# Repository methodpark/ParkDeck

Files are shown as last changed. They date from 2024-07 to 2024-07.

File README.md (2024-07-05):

# ParkDeck

## Description
ParkDeck is MethodPark's version of a streamdeck. With it you can control desktop applications on your pc or send macros for all number of purposes!

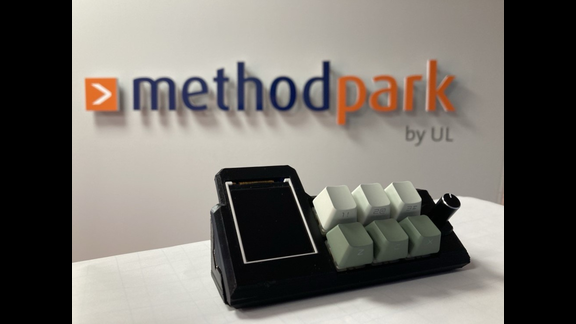
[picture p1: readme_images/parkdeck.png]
ParkDeck


In this repository you can find all information on how to build a ParkDeck. The code and the Readme are set up to control Spotify streaming.

## Prerequisite

- **Arduino IDE with a version > 2.0**
- You can check the version of your Arduino IDE by navigating to the topbar in the IDE and selecting `Help` -> `About Arduino IDE`
- Download and install the Arduino IDE following the instructions for your OS, [here](https://www.arduino.cc/en/software)

## Assembly

Place the ESP dev module on the PCB and solder it in place.

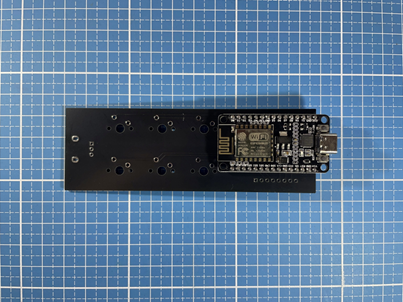
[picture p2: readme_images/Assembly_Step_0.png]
Assembly_Step_0


Flip it and place the switches and potentiometer on the PCB and solder them.

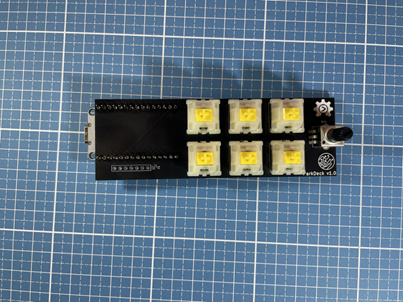
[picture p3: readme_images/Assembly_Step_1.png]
Assembly_Step_1


Place the LCD in the front half of the case. Don't forget to remove the protective peel beforehand!

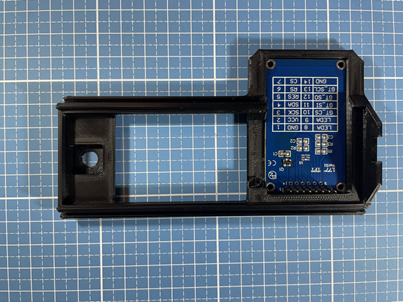
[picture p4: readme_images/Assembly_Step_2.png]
Assembly_Step_2


Place the PCB into the front half of the case and align the LCD pins. Then solder it in place.

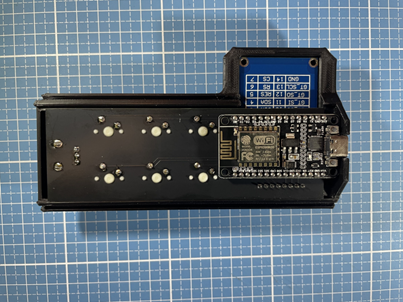
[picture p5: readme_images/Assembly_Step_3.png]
Assembly_Step_3


Slide the two halves of the case together.

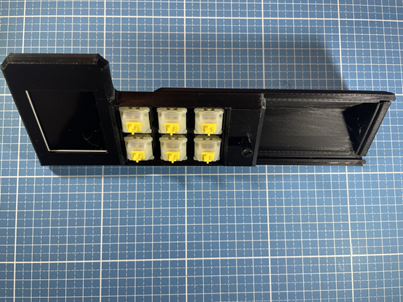
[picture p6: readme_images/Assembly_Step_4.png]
Assembly_Step_4


Choose and put the switch caps of your choice and put the potentiometer knob in place.

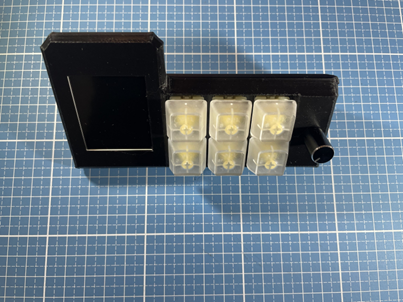
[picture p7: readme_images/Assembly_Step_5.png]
Assembly_Step_5


The hardware assembly is now done!

## Setup
- Clone this repository and open the .ino file in the Arduino IDE
- Install the following libraries by navigating to `Sketch` -> `Include Library` -> `Manage Libraries` or press `CTRL` + `SHIFT` + `I` and type in the name of the libraries:
	- `TFT_eSPI` by Bodmer
	TFT_eSPI library by Bodmer
	- `TJpg_Decoder` by Bodmer
	TJpg_Decoder
	- `ArduinoJson` by Benoit Blanchon
	ArduinoJson
- Go to the [filesystem plugin for ESP8266 repository](https://github.com/earlephilhower/arduino-littlefs-upload) and follow the installation instructions and then come back after restarting the IDE

At this point, all neccessary libraries should be installed. Next, we want to connect the ParkDeck and check that everything is working.

- Plug in your assembled ParkDeck
- In the IDE, navigate to `File` -> `Preferences`, look for `Additional Boards Manager URLs` or press `CTRL` + `,` and click the popup icon at the end of the line. Add the URL `http://arduino.esp8266.com/stable/package_esp8266com_index.json` and confirm your settings.

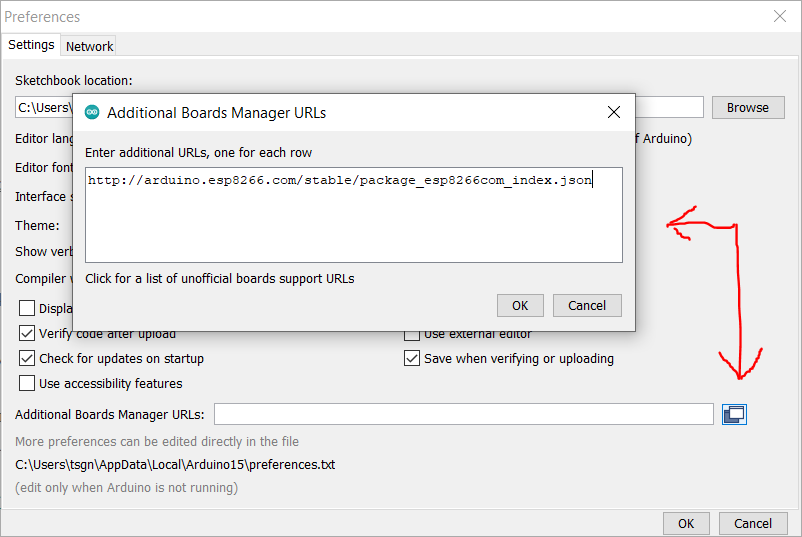
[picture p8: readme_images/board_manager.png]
Adding the ESP8266 Board Manager URL


- Navigate to `Tools` -> `Board` -> `Boards Manager...`, and install the `esp8266`
- Navigate to `Tools` -> `Board` -> `ESP8266 Boards` and select `NodeMCU 1.0 (ESP-12E Module)`
- Set `Tools` -> `CPU Frequency` to `160mhz`
- Navigate to `Tools` -> `Port` and select the correct port. This depends on where you've plugged in the ParkDeck. Find the right port by selecting one (e.g. `COM7`) and try to upload the sketch using the arrow icon in the toolbar. A success looks like this:
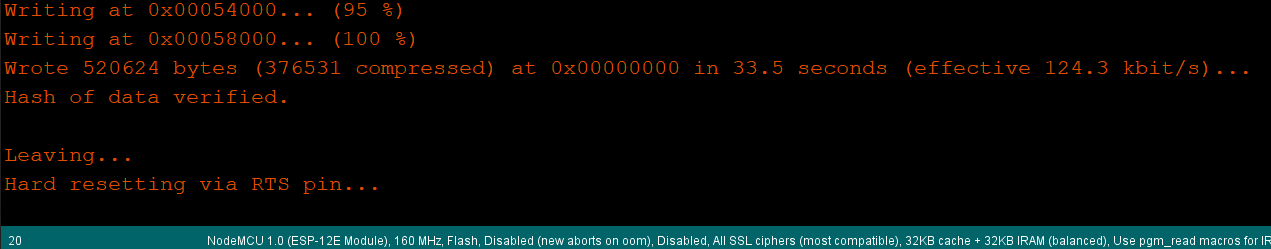
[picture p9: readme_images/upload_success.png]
Upload success

- Now you can upload the data inside the `data` folder in this repository to the ESP. Use the command `[Ctrl] + [Shift] + [P], then "Upload LittleFS to Pico/ESP8266/ESP32"` and wait for it to finish. Note: make sure that no serial monitor or serial plot is open in order for this tool to work.

Next, we need to make a few configuration changes to the libraries we've installed to make the display work.

- Open the Arduino TFT library installation folder. On Windows, it is located at `Documents\Arduino\libraries\TFT_eSPI`
- Open the `User_Setup_Select.h` file in an editor of your choice
- Add `//` in front of line 27 (`// #include <User_Setup.h)` to comment the line and uncomment by removing the `//` in line 30 to include the `User_Setups/Setup2_ST7735.h` and save your changes
TFT_eSPI_configuration
- Next, open the `Setup2_ST7735.h` file in an editor of your choice located in the folder `User_Setups` and change line 11 from `#define ST7735_REDTAB` to `#define ST7735_GREENTAB`.
- Add `#define TFT_SPI_OVERLAP` after `TFT_HEIGHT` in line 9
- Uncomment line 16 `#define TFT_RGB_ORDER TFT_RGB  // Colour order Red-Green-Blue`
- In the same file, replace lines 20 - 22 with the correct pins and save the file:
```
#define TFT_CS   PIN_D3  // Chip select control pin D8
#define TFT_DC   PIN_D8  // Data Command control pin
#define TFT_RST  PIN_D6  // Reset pin
#define TFT_MISO  PIN_MISO  // MISO
#define TFT_MOSI  PIN_MOSI  // MOSI
#define TFT_SCLK  PIN_SCLK  // CLK
```
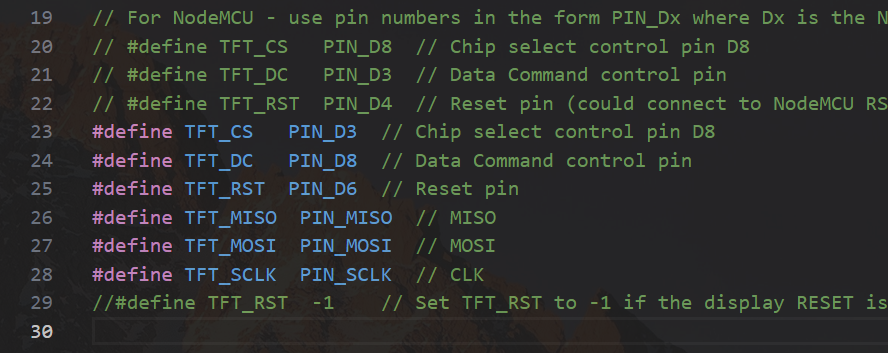
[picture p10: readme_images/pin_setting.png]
pin_setting


Congratulations! Everything should be correctly set up. The only thing left is to make sure that your ParkDeck is connected to your WIFI and make sure it works.

- In the ParkDeck.ino file edit lines 40 and 41 to your WIFI_SSID and PASSWORD.
	> Note: SSIDs are case sensitive.
- Upload the code to the ParkDeck

If it worked the screen should show its personal IP adress once the ParkDeck has rebooted.

## Spotify setup
- Go to https://developer.spotify.com/documentation/web-api and follow the instructions there to create a new app.
- When asked for a redirect URI enter `http://YOUR_ESP_IP/callback`, where `YOUR_ESP_IP` is the IP displayed on the screen of the ParkDeck in the step before.
- In the Spotify app there are client_ID as well as client_Secret, copy these to line 44 and 45 in the ParkDeck.ino file.
- Also enter the IP adress from above as `YOUR_ESP_IP` in line 46.
- Push the code once more in Arduino IDE and once your ParkDeck reboots navigate in a web browser to the IP displayed and follow the instructions.

It's done! Now you can start Spotify and enjoy the control you have with your new ParkDeck!

## Notes

- You have to authenticate on each usage (each restart)
- Skip backwards works only after the songs is playing a few seconds, the ParkDeck needs to load the album art etc.

## Original source
Credit goes to https://gitlab.com/makeitforless/spotify_controller for the idea and framework.

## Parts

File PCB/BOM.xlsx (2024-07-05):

Type | Description | # needed | Link
Display | Display | 1 | https://www.amazon.de/AZDelivery-TFT-Display-128x160-Pixeln-Arduino/dp/B07FYCKYP1/
ESP8266 | ESP8266 | 1 | https://www.amazon.de/Entwicklungsboard-RUIZHI-Schnittstelle-kompatibel-Micropython/dp/B0CLXZ9VN9/
10k Pot | Potentiometer | 1 | https://www.amazon.de/sourcing-map-Potentiometer-Varistor-Kohleschicht/dp/B07TBG7XHZ/
Knob | Potentiometer knob | 1 | https://www.amazon.de/sourcing-map-Potentiometerknopf-R%C3%A4ndelwelle-Lautst%C3%A4rkeregler/dp/B08214YZDS
Switch | Switch | 6 | https://www.amazon.de/Mechanische-Dedizierte-Professionellem-Tastaturabzieher-mechanische/dp/B096SS742W/
Switch Cap | Coloured | 6 | https://www.amazon.de/Elacgap-Profile-switches-Mechanical-Keyboard-Verschiedene-Farben/dp/B0CQ2WGP2N/ (https://www.amazon.de/Mechanische-Dedizierte-Professionellem-Tastaturabzieher-mechanische/dp/B096SS742W/)
Switch Cap | Black |  | https://www.amazon.de/Elacgap-Profile-switches-Mechanical-Keyboard-Verschiedene-Farben/dp/B0CQ2XG16M/
Switch Cap | Transparent |  | https://www.amazon.de/Elacgap-Profile-switches-Mechanical-Keyboard-Verschiedene-Farben/dp/B0CQ2Y89GQ/
Cable | Cable | 1 | https://www.amazon.de/QGhappy-Ladekabel-geflochtene-Datenkabel-Schnellladekabell-Rot/dp/B07JDP2MNB/
PCB | PCB | 1
Anti Slip | Anti Slip |  | https://www.amazon.de/Silikon-Rutschfest-Selbsthaftender-Gro%C3%9Fartig-geeignet/dp/B071CGN92T/
Resistor | Resistor | 1 | https://www.amazon.de/Innfeeltech-Toleranz-Widerstand-Projekt-Experimente/dp/B0CL73CZPQ/

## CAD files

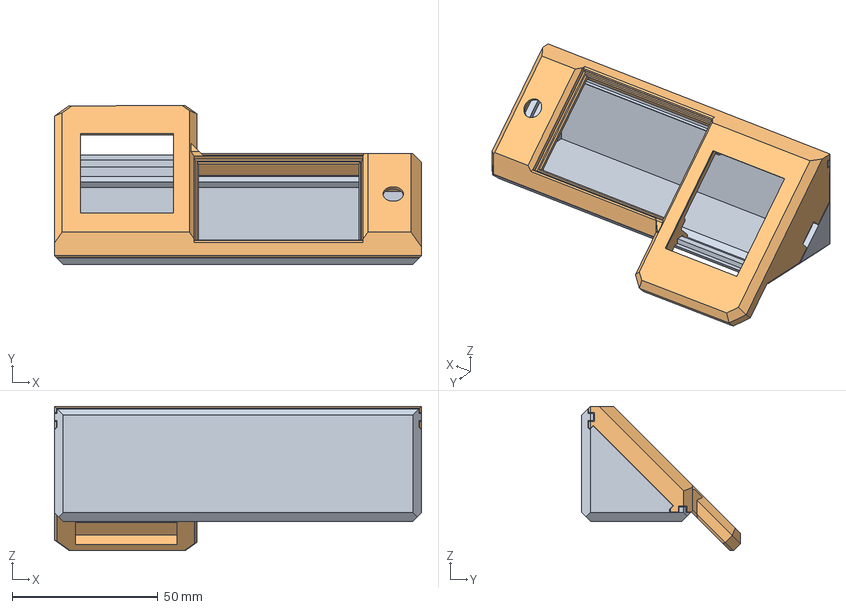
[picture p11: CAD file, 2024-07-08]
models/ParkDeck.step
125.8 x 54.5 x 49.5 mm

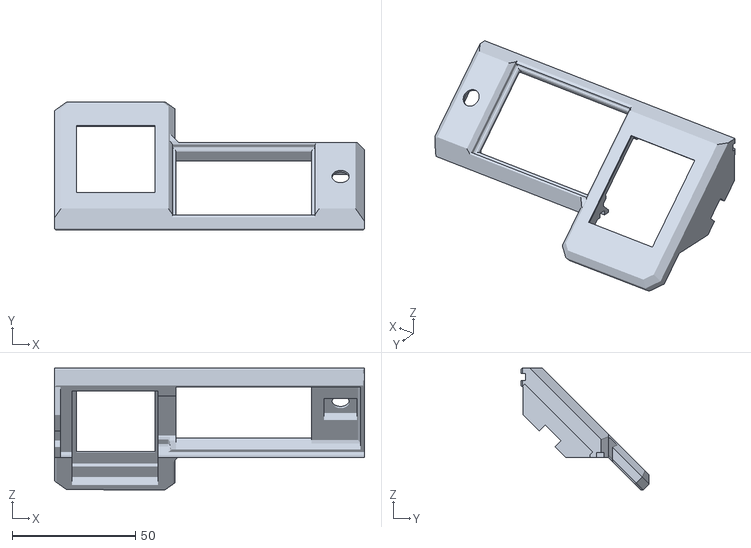
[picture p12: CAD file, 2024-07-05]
models/ParkDeck_Top.stl
125.8 x 52.1 x 49.5

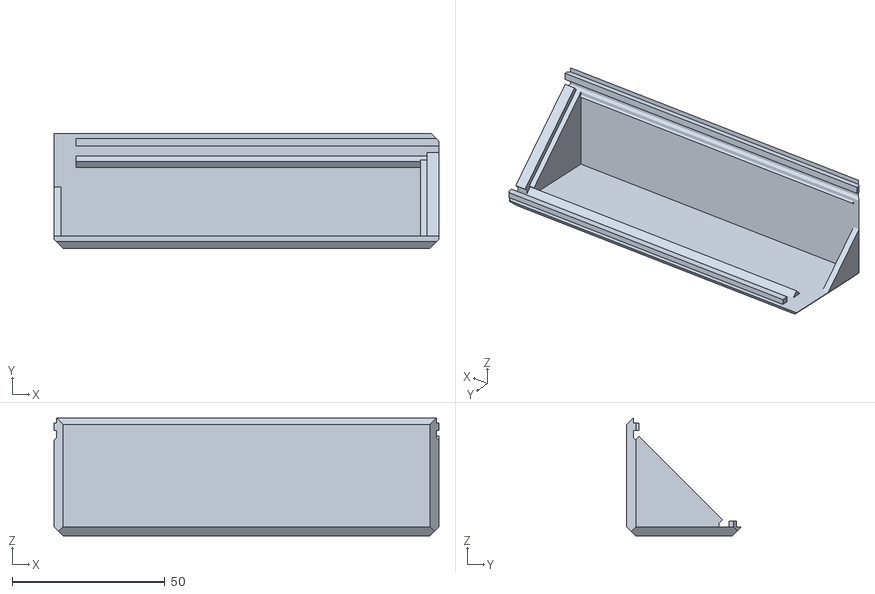
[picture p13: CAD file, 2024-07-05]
models/ParkDeck_Base.stl
125.8 x 37.5 x 38.6

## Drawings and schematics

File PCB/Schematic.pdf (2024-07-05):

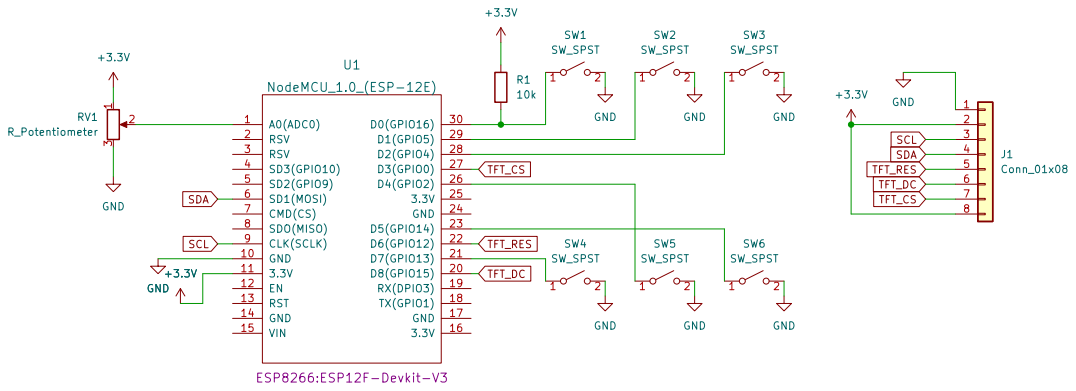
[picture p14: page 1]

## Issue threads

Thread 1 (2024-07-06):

Source file for the case

dgrabla, 2024-07-06:
Terrific project, thanks

Hey @LeJokester any chance we can get a step file || onshape link || fusion360 to do remixes of the case?
I would like to hook it somehow under the display and use it 'upside down'.
I could not find the model on printables or thingiverse.

Best

LeJokester, 2024-07-08:
Glad you like it! I added the case model as step and fbx files, I hope that helps :)

dgrabla, 2024-07-08:
Great, thanks!

Closed 2024-07-08.

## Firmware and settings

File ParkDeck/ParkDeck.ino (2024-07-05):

/*========================================
|Include all libraries needed for program|
========================================*/

// Include the jpeg decoder library
#include <TJpg_Decoder.h>

// Include LittleFS
#include <FS.h>
#include <LittleFS.h>

//Include JSON
#include <ArduinoJson.h>

//Include base 64 encode
#include <base64.h>

// Include WiFi and http client
#include <ESP8266WiFi.h>
#include <ESP8266HTTPClient.h>
#include <ESP8266WebServer.h>
#include <WiFiClientSecureBearSSL.h>

// Load tabs attached to this sketch
#include "List_SPIFFS.h"
#include "Web_Fetch.h"
#include "index.h"
#include "SpotifyConnection.h"

// Include the TFT library https://github.com/Bodmer/TFT_eSPI
#include <SPI.h>
#include <TFT_eSPI.h>

/*=========================
|User modifiable variables|
=========================*/

// WiFi credentials
#define WIFI_SSID "WIFI_SSID"
#define PASSWORD "PASSWORD"

// Spotify API credentials
#define CLIENT_ID "CLIENT_ID"
#define CLIENT_SECRET "CLIENT_SECRET"
#define REDIRECT_URI "http://YOUR_ESP_IP/callback"

/*=========================
|Non - modifiable variables|
==========================*/

//Vars for keys, play state, last song, etc.
bool buttonStates[] = { 1, 1, 1, 1, 1, 1 };
int debounceDelay = 50;
unsigned long debounceTimes[] = { 0, 0, 0, 0, 0, 0 };
int buttonPins[] = { D0, D1, D2, D7, D4, D5 };
int trackRefreshTimeInMilliseconds = 5000;

//Object instances
ESP8266WebServer server(80);  //Server on port 80
TFT_eSPI tft = TFT_eSPI();  // Invoke custom library
SpotifyConnection spotifyConnection(CLIENT_ID, CLIENT_SECRET, REDIRECT_URI, tft);

int imageOffsetX = 26, imageOffsetY = 20;

long timeLoop;
long refreshLoop;
bool serverOn = true;

//Web server callbacks
void handleRoot() {
  Serial.println("handling root");
  char page[500];
  sprintf(page, mainPage, CLIENT_ID, REDIRECT_URI);
  server.send(200, "text/html", String(page) + "\r\n");  //Send web page
}

void handleCallbackPage() {
  if (!spotifyConnection.accessTokenSet) {
    if (server.arg("code") == "") {  //Parameter not found
      char page[500];
      sprintf(page, errorPage, CLIENT_ID, REDIRECT_URI);
      server.send(200, "text/html", String(page));  //Send web page
    } else {
      //Parameter found
      if (spotifyConnection.getUserCode(server.arg("code"))) {
        server.send(200, "text/html", "Spotify setup complete Auth refresh in :" + String(spotifyConnection.tokenExpireTime));
      } else {
        char page[500];
        sprintf(page, errorPage, CLIENT_ID, REDIRECT_URI);
        server.send(200, "text/html", String(page));  //Send web page
      }
    }
  } else {
    server.send(200, "text/html", "Spotify setup complete");
  }
}

// This next function will be called during decoding of the jpeg file to
// render each block to the TFT.  If you use a different TFT library
// you will need to adapt this function to suit.
bool tft_output(int16_t x, int16_t y, uint16_t w, uint16_t h, uint16_t *bitmap) {
  // Stop further decoding as image is running off bottom of screen
  if (y >= tft.height()) {
    return 0;
  }

  // This function will clip the image block rendering automatically at the TFT boundaries
  tft.pushImage(x, y, w, h, bitmap);

  // Return 1 to decode next block
  return 1;
}

/*==============
|Setup function|
==============*/
// * Sets up WiFi
// * Initializes screen
// * Shows Ip on screen

void setup() {
  Serial.begin(115200);

  // Initialise LittleFS
  if (!LittleFS.begin()) {
    Serial.println("LittleFS initialisation failed!");
    while (1) yield();  // Stay here twiddling thumbs waiting
  }
  Serial.println("\r\nInitialisation done.");

  // Initialise the TFT
  tft.begin();
  tft.fillScreen(TFT_BLACK);
  tft.setRotation(2);
  // The jpeg image can be scaled by a factor of 1, 2, 4, or 8
  TJpgDec.setJpgScale(4);

  // The byte order can be swapped (set true for TFT_eSPI)
  TJpgDec.setSwapBytes(true);

  // The decoder must be given the exact name of the rendering function above
  TJpgDec.setCallback(tft_output);

  WiFi.begin(WIFI_SSID, PASSWORD);
  while (WiFi.status() != WL_CONNECTED) {
    delay(1000);
    Serial.println("Connecting to WiFi...");
  }
  Serial.println("Connected to WiFi\n Ip is: ");
  Serial.println(WiFi.localIP());

  server.on("/", handleRoot);                  //Which routine to handle at root location
  server.on("/callback", handleCallbackPage);  //Which routine to handle at root location
  server.begin();                              //Start server
  Serial.println("HTTP server started");
  for (int i = 0; i < 6; i++) {
    pinMode(buttonPins[i], INPUT_PULLUP);
  }

  tft.println(WiFi.localIP());
  Serial.println("Setup done");
}

void loop() {
  if (!spotifyConnection.accessTokenSet) {
    server.handleClient();
    return;
  }

  if (serverOn) {
    server.close();
    serverOn = false;
  }

  if ((millis() - spotifyConnection.tokenStartTime) / 1000 > spotifyConnection.tokenExpireTime) {
    Serial.println("refreshing token");
    if (spotifyConnection.refreshAuth()) {
      Serial.println("refreshed token");
    }
  }

  if ((millis() - refreshLoop) > trackRefreshTimeInMilliseconds) {
    spotifyConnection.getTrackInfo();

    refreshLoop = millis();
  }

  for (int i = 0; i < 6; i++) {
    int reading = digitalRead(buttonPins[i]);
    if (reading != buttonStates[i]) {
      if (millis() - debounceTimes[i] > debounceDelay) {
        buttonStates[i] = reading;
        if (reading == LOW) {
          switch (i) {
            case 0:
              Serial.println("Button 0: not in use");
              //listSPIFFS();
              break;
            case 1:
              Serial.println("Button 1: toggleLiked");
              spotifyConnection.toggleLiked(spotifyConnection.currentSong.Id);
              break;
            case 2:
              Serial.println("Button 2: not in use");
              break;
            case 3:
              Serial.println("Button 3: skipBack");
              spotifyConnection.skipBack();
              break;
            case 4:
              Serial.println("Button 4 togglePlay");
              spotifyConnection.togglePlay();
              break;
            case 5:
              Serial.println("Button 5 skipForward");
              spotifyConnection.skipForward();
              break;
            default:
              break;
          }
        }
        debounceTimes[i] = millis();
      }
    }
  }

  int volumeRequest = map(analogRead(A0), 0, 1023, 100, 0);
  if (abs(volumeRequest - spotifyConnection.currVol) > 2) {
    spotifyConnection.adjustVolume(volumeRequest);
  }
  timeLoop = millis();
}

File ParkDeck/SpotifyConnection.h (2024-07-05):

// Include the TFT library https://github.com/Bodmer/TFT_eSPI
#include <SPI.h>
#include <TFT_eSPI.h>


class SpotifyConnection {
public:
  SpotifyConnection(String _CLIENT_ID, String _CLIENT_SECRET, String _REDIRECT_URI, TFT_eSPI &_tft): tft (_tft) {
    CLIENT_ID = _CLIENT_ID;
    CLIENT_SECRET = _CLIENT_SECRET;
    REDIRECT_URI = _REDIRECT_URI;
    client = std::make_unique<BearSSL::WiFiClientSecure>();
    client->setInsecure();

    for (int i = 0; i < 10; i++) {
      parts[i] = (char *)malloc(sizeof(char) * 20);
    }
  }

  struct songDetails {
    int durationMs;
    String album;
    String artist;
    String song;
    String Id;
    bool isLiked;
  };

  String getValue(HTTPClient &http, String key) {
    bool found = false, look = false, seek = true;
    int ind = 0;
    String ret_str = "";

    int len = http.getSize();
    char char_buff[1];
    WiFiClient *stream = http.getStreamPtr();
    while (http.connected() && (len > 0 || len == -1)) {
      size_t size = stream->available();
      if (size) {
        int c = stream->readBytes(char_buff, ((size > sizeof(char_buff)) ? sizeof(char_buff) : size));
        if (found) {
          if (seek && char_buff[0] != ':') {
            continue;
          } else if (char_buff[0] != '\n') {
            if (seek && char_buff[0] == ':') {
              seek = false;
              int c = stream->readBytes(char_buff, 1);
            } else {
              ret_str += char_buff[0];
            }
          } else {
            break;
          }
        } else if ((!look) && (char_buff[0] == key[0])) {
          look = true;
          ind = 1;
        } else if (look && (char_buff[0] == key[ind])) {
          ind++;
          if (ind == key.length()) {
            found = true;
          }
        } else if (look && (char_buff[0] != key[ind])) {
          ind = 0;
          look = false;
        }
      }
    }

    if (*(ret_str.end() - 1) == ',') {
      ret_str = ret_str.substring(0, ret_str.length() - 1);
    }

    return ret_str;
  }

  void printSplitString(String text, int maxLineSize, int yPos) {
    int currentWordStart = 0;
    int spacedCounter = 0;
    int spaceIndex = text.indexOf(" ");

    while (spaceIndex != -1) {
      char *part = parts[spacedCounter];
      sprintf(part, text.substring(currentWordStart, spaceIndex).c_str());
      currentWordStart = spaceIndex;
      spacedCounter++;
      spaceIndex = text.indexOf(" ", spaceIndex + 1);
    }

    char *part = parts[spacedCounter];
    sprintf(part, text.substring(currentWordStart, text.length()).c_str());
    currentWordStart = spaceIndex;
    size_t counter = 0;
    currentWordStart = 0;
    while (counter <= spacedCounter) {
      char printable[maxLineSize];
      char *printablePointer = printable;
      // sprintf in word at counter always
      sprintf(printablePointer, parts[counter]);
      //get length of first word
      int currentLen = 0;
      while (parts[counter][currentLen] != '\0') {
        currentLen++;
        printablePointer++;
      }
      counter++;
      while (counter <= spacedCounter) {
        int nextLen = 0;
        while (parts[counter][nextLen] != '\0') {
          nextLen++;
        }
        if (currentLen + nextLen > maxLineSize) {
          break;
        }
        sprintf(printablePointer, parts[counter]);
        currentLen += nextLen;
        printablePointer += nextLen;
        counter++;
      }

      String output = String(printable);

      if (output[0] == ' ') {
        output = output.substring(1);
      }

      tft.setCursor((int)(tft.width() / 2 - tft.textWidth(output) / 2), tft.getCursorY());
      tft.println(output);
    }
  }

  bool getUserCode(String serverCode) {
    https.begin(*client, "https://accounts.spotify.com/api/token");
    String auth = "Basic " + base64::encode(String(CLIENT_ID) + ":" + String(CLIENT_SECRET));
    https.addHeader("Authorization", auth);
    https.addHeader("Content-Type", "application/x-www-form-urlencoded");
    String requestBody = "grant_type=authorization_code&code=" + serverCode + "&redirect_uri=" + String(REDIRECT_URI);
    // Send the POST request to the Spotify API
    int httpResponseCode = https.POST(requestBody);
    // Check if the request was successful
    if (httpResponseCode == HTTP_CODE_OK) {
      String response = https.getString();
      DynamicJsonDocument doc(1024);
      deserializeJson(doc, response);
      accessToken = String((const char *)doc["access_token"]);
      refreshToken = String((const char *)doc["refresh_token"]);
      tokenExpireTime = doc["expires_in"];
      tokenStartTime = millis();
      accessTokenSet = true;
      Serial.println(accessToken);
      Serial.println(refreshToken);
    } else {
      Serial.println(https.getString());
    }
    // Disconnect from the Spotify API
    https.end();
    return accessTokenSet;
  }

  bool refreshAuth() {
    https.begin(*client, "https://accounts.spotify.com/api/token");
    String auth = "Basic " + base64::encode(String(CLIENT_ID) + ":" + String(CLIENT_SECRET));
    https.addHeader("Authorization", auth);
    https.addHeader("Content-Type", "application/x-www-form-urlencoded");
    String requestBody = "grant_type=refresh_token&refresh_token=" + String(refreshToken);
    // Send the POST request to the Spotify API
    int httpResponseCode = https.POST(requestBody);
    accessTokenSet = false;
    // Check if the request was successful
    if (httpResponseCode == HTTP_CODE_OK) {
      String response = https.getString();
      DynamicJsonDocument doc(1024);
      deserializeJson(doc, response);
      accessToken = String((const char *)doc["access_token"]);
      tokenExpireTime = doc["expires_in"];
      tokenStartTime = millis();
      accessTokenSet = true;
      Serial.println(accessToken);
      Serial.println(refreshToken);
    } else {
      Serial.println(https.getString());
    }
    // Disconnect from the Spotify API
    https.end();
    return accessTokenSet;
  }

  bool getTrackInfo() {
    String url = "https://api.spotify.com/v1/me/player/currently-playing";
    https.useHTTP10(true);
    https.begin(*client, url);
    String auth = "Bearer " + String(accessToken);
    https.addHeader("Authorization", auth);
    int httpResponseCode = https.GET();
    bool success = false;
    String songId = "";
    bool refresh = false;
    // Check if the request was successful
    if (httpResponseCode == 200) {
      String currentSongProgress = getValue(https, "progress_ms");
      currentSongPositionMs = currentSongProgress.toFloat();
      String imageLink = "";
      while (imageLink.indexOf("image") == -1) {
        String height = getValue(https, "height");
        if (height.toInt() > 300) {
          imageLink = "";
          continue;
        }
        imageLink = getValue(https, "url");
      }
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

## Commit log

2024-07-05 Initial commit to public repository
    [BOM.xlsx, ParkDeck_Base.stl, ParkDeck_Top.stl]
2024-07-08 added case model source files
    [ParkDeck.step]
